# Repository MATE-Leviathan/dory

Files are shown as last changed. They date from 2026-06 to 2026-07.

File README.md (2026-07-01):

# Dory

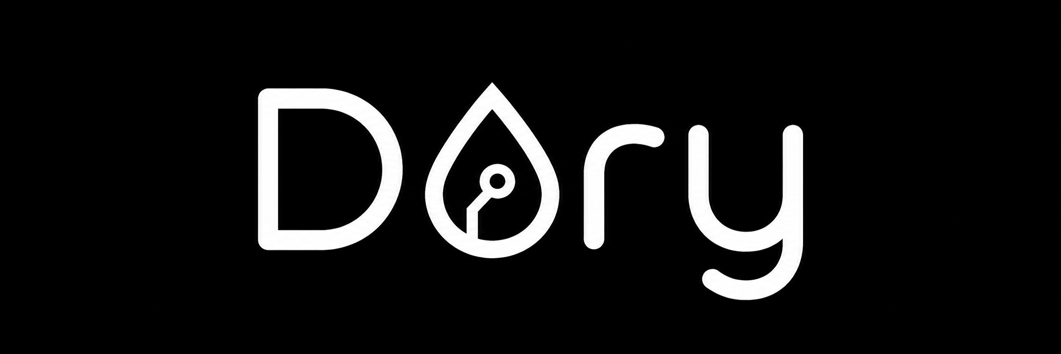
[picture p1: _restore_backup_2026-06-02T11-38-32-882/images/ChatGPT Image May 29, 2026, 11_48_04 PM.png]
Dory project logo


A custom control and power distribution board for NCSSM Morganton Robotics.

NCSSM Morganton Robotics

## Why this exists

This board started as a wiring problem.

On the robot, too many things were being connected with loose jumper wires, splitters, adapters, and one-off harnesses. It worked, but it was annoying to build, annoying to trace, and even more annoying to debug when something came loose. Every extra wire was another failure point, and every repair meant spending time figuring out which connection had moved instead of working on the robot.

Float PCB is meant to clean that up. It brings the common controller, power, sensor, light, and debug connections onto one board so the robot is easier to assemble, easier to service, and less dependent on fragile wiring.

## Board evolution

The design went through several revisions while the board moved from a simple rectangular breakout toward the current round layout with cleaner connector placement, clearer labels, and more intentional branding.

Top-side PCB revision collage

Bottom-side PCB revision collage

## Features

- **ESP32-S3 controller** using an ESP32-S3-WROOM-1U module for onboard control and wireless-capable development.
- **External antenna support** through the ESP32-S3-WROOM-1U module for more flexible radio placement.
- **USB-C interface** for programming, debugging, and convenient bench access.
- **XT30 battery input** for a more robust main power connector than loose leads.
- **64 mm round board outline** for a compact layout that fits cleanly into the robot.
- **4-layer PCB stackup** with front/back signal layers and two internal power layers.
- **5V and 3.3V regulation** using TPSM863252 power modules.
- **ESP-controlled 5V enable** so software can turn the 5V rail on or off when needed.
- **Onboard buzzer** for audible alerts, even when the board is mounted inside the robot.
- **External light output** for driving a Blue Robotics-style indicator or robot status light.
- **Dual I2C ports** on JST-XH connectors for cleaner sensor wiring.
- **Robot I/O connectors** for switch, light, servo, buzzer, and miscellaneous expansion signals.
- **Battery sensing** through a resistor divider and dedicated `BATT_ADC` test point.
- **Status LEDs** for battery, 5V, and 3.3V rails.
- **USB ESD protection** on the USB data lines.
- **Debug/test access** with labeled test points for power rails, boot, enable, I2C, and ground.
- **Mechanical mounting** with three M2 mounting holes.

## Hardware overview

The board is built around an ESP32-S3-WROOM-1U module and breaks out the useful robot-facing signals to keyed or serviceable connectors. The PCB is a 64 mm diameter, 4-layer circular board with front and back signal routing plus two internal power layers. Power enters through an XT30 connector, then the onboard regulators generate the rails needed by the controller and peripherals.

The intent is not to replace every subsystem on the robot. The goal is to provide a cleaner central board for the connections that otherwise turn into messy wiring: power, I2C devices, lights, switches, a buzzer, servo control, battery monitoring, and spare expansion lines.

## Work in progress

The current plan is to use the onboard ESP32 as the robot-side controller and pair it with a separate ESP32-based base station. The base station will communicate with the ESP32 on the Float PCB, giving the robot a cleaner wireless control/debug path without needing to plug directly into the board every time.

An accompanying web interface is also planned. The site will be built with Svelte and use Web Serial so a laptop can talk to the ESP32 base station directly from the browser. The goal is to make setup, monitoring, and debugging accessible without requiring a custom desktop app.

## Repository contents

- `float_pcb.kicad_pro` — KiCad project file.
- `float_pcb.kicad_sch` — schematic source.
- `float_pcb.kicad_pcb` — PCB layout source.
- `jlcpcb/production_files/` — generated BOM, CPL, and Gerber ZIP for JLCPCB.
- `jlcpcb/gerber/` — expanded Gerber and drill outputs.
- `float_pcb.csv` — project BOM/export data.
- `digikey/order.csv` — DigiKey ordering file.
- `images/` — README and board/team branding assets.

## Manufacturing

The repository includes production outputs under `jlcpcb/production_files/`:

- `GERBER-float_pcb.zip`
- `BOM-float_pcb.csv`
- `CPL-float_pcb.csv`

Before ordering, re-open the project in KiCad, refill zones, run DRC/ERC, and regenerate production files from the latest schematic and PCB layout. The checked-in files are useful for handoff, but the KiCad sources should be treated as the source of truth.

For component ordering, use `digikey/order.csv` as the DigiKey order file.

## Known issues

- One of the I2C ports is about 0.025 mm off in the Z direction. This is only for people with OCD like me; it should not matter for normal assembly.
- The fancy QFN buck converter packages are hard to solder by hand. If you want to build this board, make sure you have solder paste, reflow, and patience, or redesign that power stage around something friendlier like a SOT-23 package.

## Development notes

- Designed in KiCad.
- Uses mostly SMD passives with JST-XH, XT30, USB-C, and pin-header connections.
- Includes test points for bring-up and debugging.
- Intended for robotics use where reliability and serviceability matter more than minimizing every connector or square millimeter.

## Team

Built for NCSSM Morganton Robotics as a practical fix for too much robot wiring.

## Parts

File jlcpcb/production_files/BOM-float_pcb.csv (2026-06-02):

Comment | Designator | Footprint | LCSC | Quantity
Light | J6 | JST_XH_B2B-XH-A_1x02_P2.50mm_Vertical |  | 1
Switch | J1 | JST_XH_B2B-XH-A_1x02_P2.50mm_Vertical |  | 1
22u | C14 | C_0603_1608Metric |  | 1
100n | C7 | C_0603_1608Metric |  | 1
28k7 | R6 | R_0603_1608Metric |  | 1
AO3400A | Q1 | SOT-23 |  | 1
22p | C4 | C_0603_1608Metric |  | 1
5V | D3 | LED_0603_1608Metric |  | 1
2k2 | R16 | R_0603_1608Metric |  | 1
100n | C2 | C_0603_1608Metric |  | 1
5k1 | R11 | R_0603_1608Metric |  | 1
10n | C3 | C_0603_1608Metric |  | 1
10k | R7 | R_0603_1608Metric |  | 1
33u | C5 | C_0805_2012Metric |  | 1
TPSM863252 | U2 | TPSM86325x_RDX0007A |  | 1
100n | C13 | C_0603_1608Metric |  | 1
1u | C12 | C_0603_1608Metric |  | 1
10k | R3 | R_0603_1608Metric |  | 1
220k | R8 | R_0603_1608Metric |  | 1
SW_Push | BOOT1 | SW_SPST_TL3342 |  | 1
10u | C6 | C_0805_2012Metric |  | 1
10k | R12 | R_0603_1608Metric |  | 1
4k7 | R13 | R_0603_1608Metric |  | 1
28k7 | R2 | R_0603_1608Metric |  | 1
Batt | J7 | AMASS_XT30U-M_1x02_P5.0mm_Vertical |  | 1
33u | C10 | C_0805_2012Metric |  | 1
4k7 | R14 | R_0603_1608Metric |  | 1
135k | R4 | R_0603_1608Metric |  | 1
10u | C1 | C_0805_2012Metric |  | 1
4k7 | R1 | R_0603_1608Metric |  | 1
USB_C | J3 | USB_C_Receptacle_GCT_USB4105-xx-A_16P_TopMnt_Horizontal |  | 1
30k | R9 | R_0603_1608Metric |  | 1
1k | R15 | R_0603_1608Metric |  | 1
3V3 | D2 | LED_0603_1608Metric |  | 1
TPSM863252 | U1 | TPSM86325x_RDX0007A |  | 1
10n | C8 | C_0603_1608Metric |  | 1
I2C | J5 | JST_XH_B4B-XH-A_1x04_P2.50mm_Vertical |  | 1
5k1 | R10 | R_0603_1608Metric |  | 1
30k | R5 | R_0603_1608Metric |  | 1
22p | C9 | C_0603_1608Metric |  | 1
BATT | D1 | LED_0603_1608Metric |  | 1
SW_Push | ENABLE1 | SW_SPST_TL3342 |  | 1
10k | R17 | R_0603_1608Metric |  | 1
4k7 | R19 | R_0603_1608Metric |  | 1
4k7 | R18 | R_0603_1608Metric |  | 1
I2C | J9 | JST_XH_B4B-XH-A_1x04_P2.50mm_Vertical |  | 1
10k | R20 | R_0603_1608Metric |  | 1
AO3400A | Q2 | SOT-23 |  | 1
AT-1127-ST-2-R | LS1 | XDCR_AT-1127-ST-2-R |  | 1
Conn_01x03 | J4 | JST_XH_B3B-XH-A_1x03_P2.50mm_Vertical |  | 1
ESP32-S3-WROOM-1 | U4 | ESP32-S3-WROOM-1U |  | 1
Conn_01x04 | J2 | PinHeader_1x04_P2.54mm_Vertical |  | 1
BATT | TP4 | TestPoint_Pad_D1.5mm |  | 1
GND | TP3 | TestPoint_Pad_D1.5mm |  | 1
3V3 | TP2 | TestPoint_Pad_D1.5mm |  | 1
5V | TP1 | TestPoint_Pad_D1.5mm |  | 1
USBLC6-2SC6 | U3 | SOT-23-6 |  | 1
USBLC6-4SC6 | U5 | SOT-23-6 |  | 1
USBLC6-4SC6 | U6 | SOT-23-6 |  | 1
TBD | R26 | R_0603_1608Metric |  | 1
10k | R25 | R_0603_1608Metric |  | 1
10k | R24 | R_0603_1608Metric |  | 1
10k | R23 | R_0603_1608Metric |  | 1
10k | R22 | R_0603_1608Metric |  | 1
0 | R21 | R_0603_1608Metric |  | 1
EN | TP10 | TestPoint_Pad_D1.5mm |  | 1
SDA2 | TP6 | TestPoint_Pad_D1.5mm |  | 1
BOOT | TP9 | TestPoint_Pad_D1.5mm |  | 1
SCL2 | TP5 | TestPoint_Pad_D1.5mm |  | 1
SDA2 | TP7 | TestPoint_Pad_D1.5mm |  | 1
SCL1 | TP8 | TestPoint_Pad_D1.5mm |  | 1

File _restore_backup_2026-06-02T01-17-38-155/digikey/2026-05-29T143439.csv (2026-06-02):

Index | Quantity | Part Number | Manufacturer Part Number | Description | Customer Reference | Available | Backorder | Unit Price | Extended Price USD
1 | 10 | 296-TPSM863252RDXRCT-ND | TPSM863252RDXR | 3-V TO 17-V INPUT VOLTAGE 3-A E |  | 10 | 0 | 2.01900 | 20.19
2 | 100 | 311-10.0KHRCT-ND | RC0603FR-0710KL | RES 10K OHM 1% 1/10W 0603 |  | 100 | 0 | 0.01220 | 1.22
3 | 100 | 160-1447-1-ND | LTST-C191KRKT | LED RED CLEAR SMD |  | 100 | 0 | 0.04740 | 4.74
4 | 10 | 785-1000-1-ND | AO3400A | MOSFET N-CH 30V 5.7A SOT23-3L |  | 10 | 0 | 0.32200 | 3.22
5 | 100 | 311-4.7KGRCT-ND | RC0603JR-074K7L | RES 4.7K OHM 5% 1/10W 0603 |  | 100 | 0 | 0.01080 | 1.08
6 | 10 | EG5470CT-ND | TL3342F260QG | SWITCH TACTILE SPST-NO 0.05A 12V |  | 10 | 0 | 0.50600 | 5.06
7 | 10 | 311-28.7KHRCT-ND | RC0603FR-0728K7L | RES 28.7K OHM 1% 1/10W 0603 |  | 10 | 0 | 0.02500 | 0.25
8 | 10 | 311-30.0KHRCT-ND | RC0603FR-0730KL | RES 30K OHM 1% 1/10W 0603 |  | 10 | 0 | 0.02500 | 0.25
9 | 10 | 311-5.10KHRCT-ND | RC0603FR-075K1L | RES 5.1K OHM 1% 1/10W 0603 |  | 10 | 0 | 0.02500 | 0.25
10 | 3 | 1965-ESP32-S3-WROOM-1U-N8R8CT-ND | ESP32-S3-WROOM-1U-N8R8 | RF TXRX MOD BLUETOOTH U.FL SMD |  | 3 | 0 | 6.32000 | 18.96
11 | 5 | 2073-USB4105-GF-ACT-ND | USB4105-GF-A | CONN RCP USB2.0 TYP C 16P SMD RA |  | 5 | 0 | 0.80000 | 4.00
12 | 3 | 668-1463-ND | AT-1127-ST-2-R | BUZZER MAGNETIC 3V 9MM TH |  | 3 | 0 | 1.09000 | 3.27
13 | 10 | 311-30.0KHRCT-ND | RC0603FR-0730KL | RES 30K OHM 1% 1/10W 0603 |  | 10 | 0 | 0.02500 | 0.25
14 | 10 | 311-1.00KHRCT-ND | RC0603FR-071KL | RES 1K OHM 1% 1/10W 0603 |  | 10 | 0 | 0.02500 | 0.25
15 | 10 | 311-2.20KHRCT-ND | RC0603FR-072K2L | RES 2.2K OHM 1% 1/10W 0603 |  | 10 | 0 | 0.02500 | 0.25
16 | 10 | 311-220KHRCT-ND | RC0603FR-07220KL | RES 220K OHM 1% 1/10W 0603 |  | 10 | 0 | 0.02500 | 0.25
17 | 10 | 13-RT0603BRD07135KLCT-ND | RT0603BRD07135KL | RES SMD 135K OHM 0.1% 1/10W 0603 |  | 10 | 0 | 0.06700 | 0.67
18 | 10 | 1276-1096-1-ND | CL21A106KOQNNNE | CAP CER 10UF 16V X5R 0805 |  | 10 | 0 | 0.05400 | 0.54
19 | 10 | 1276-1070-1-ND | CL10C330JB8NNNC | CAP CER 33PF 50V C0G/NP0 0603 |  | 10 | 0 | 0.03800 | 0.38
20 | 10 | 1276-1023-1-ND | CL10C220JB8NNNC | CAP CER 22PF 50V C0G/NP0 0603 |  | 10 | 0 | 0.03800 | 0.38
21 | 10 | 1276-1274-1-ND | CL10A226MP8NUNE | CAP CER 22UF 10V X5R 0603 |  | 10 | 0 | 0.08900 | 0.89
22 | 10 | 1276-1019-1-ND | CL10B105KO8NNNC | CAP CER 1UF 16V X7R 0603 |  | 10 | 0 | 0.03700 | 0.37
23 | 10 | 1276-1000-1-ND | CL10B104KB8NNNC | CAP CER 0.1UF 50V X7R 0603 |  | 10 | 0 | 0.02700 | 0.27
24 | 10 | 1276-1009-1-ND | CL10B103KB8NNNC | CAP CER 10000PF 50V X7R 0603 |  | 10 | 0 | 0.02500 | 0.25

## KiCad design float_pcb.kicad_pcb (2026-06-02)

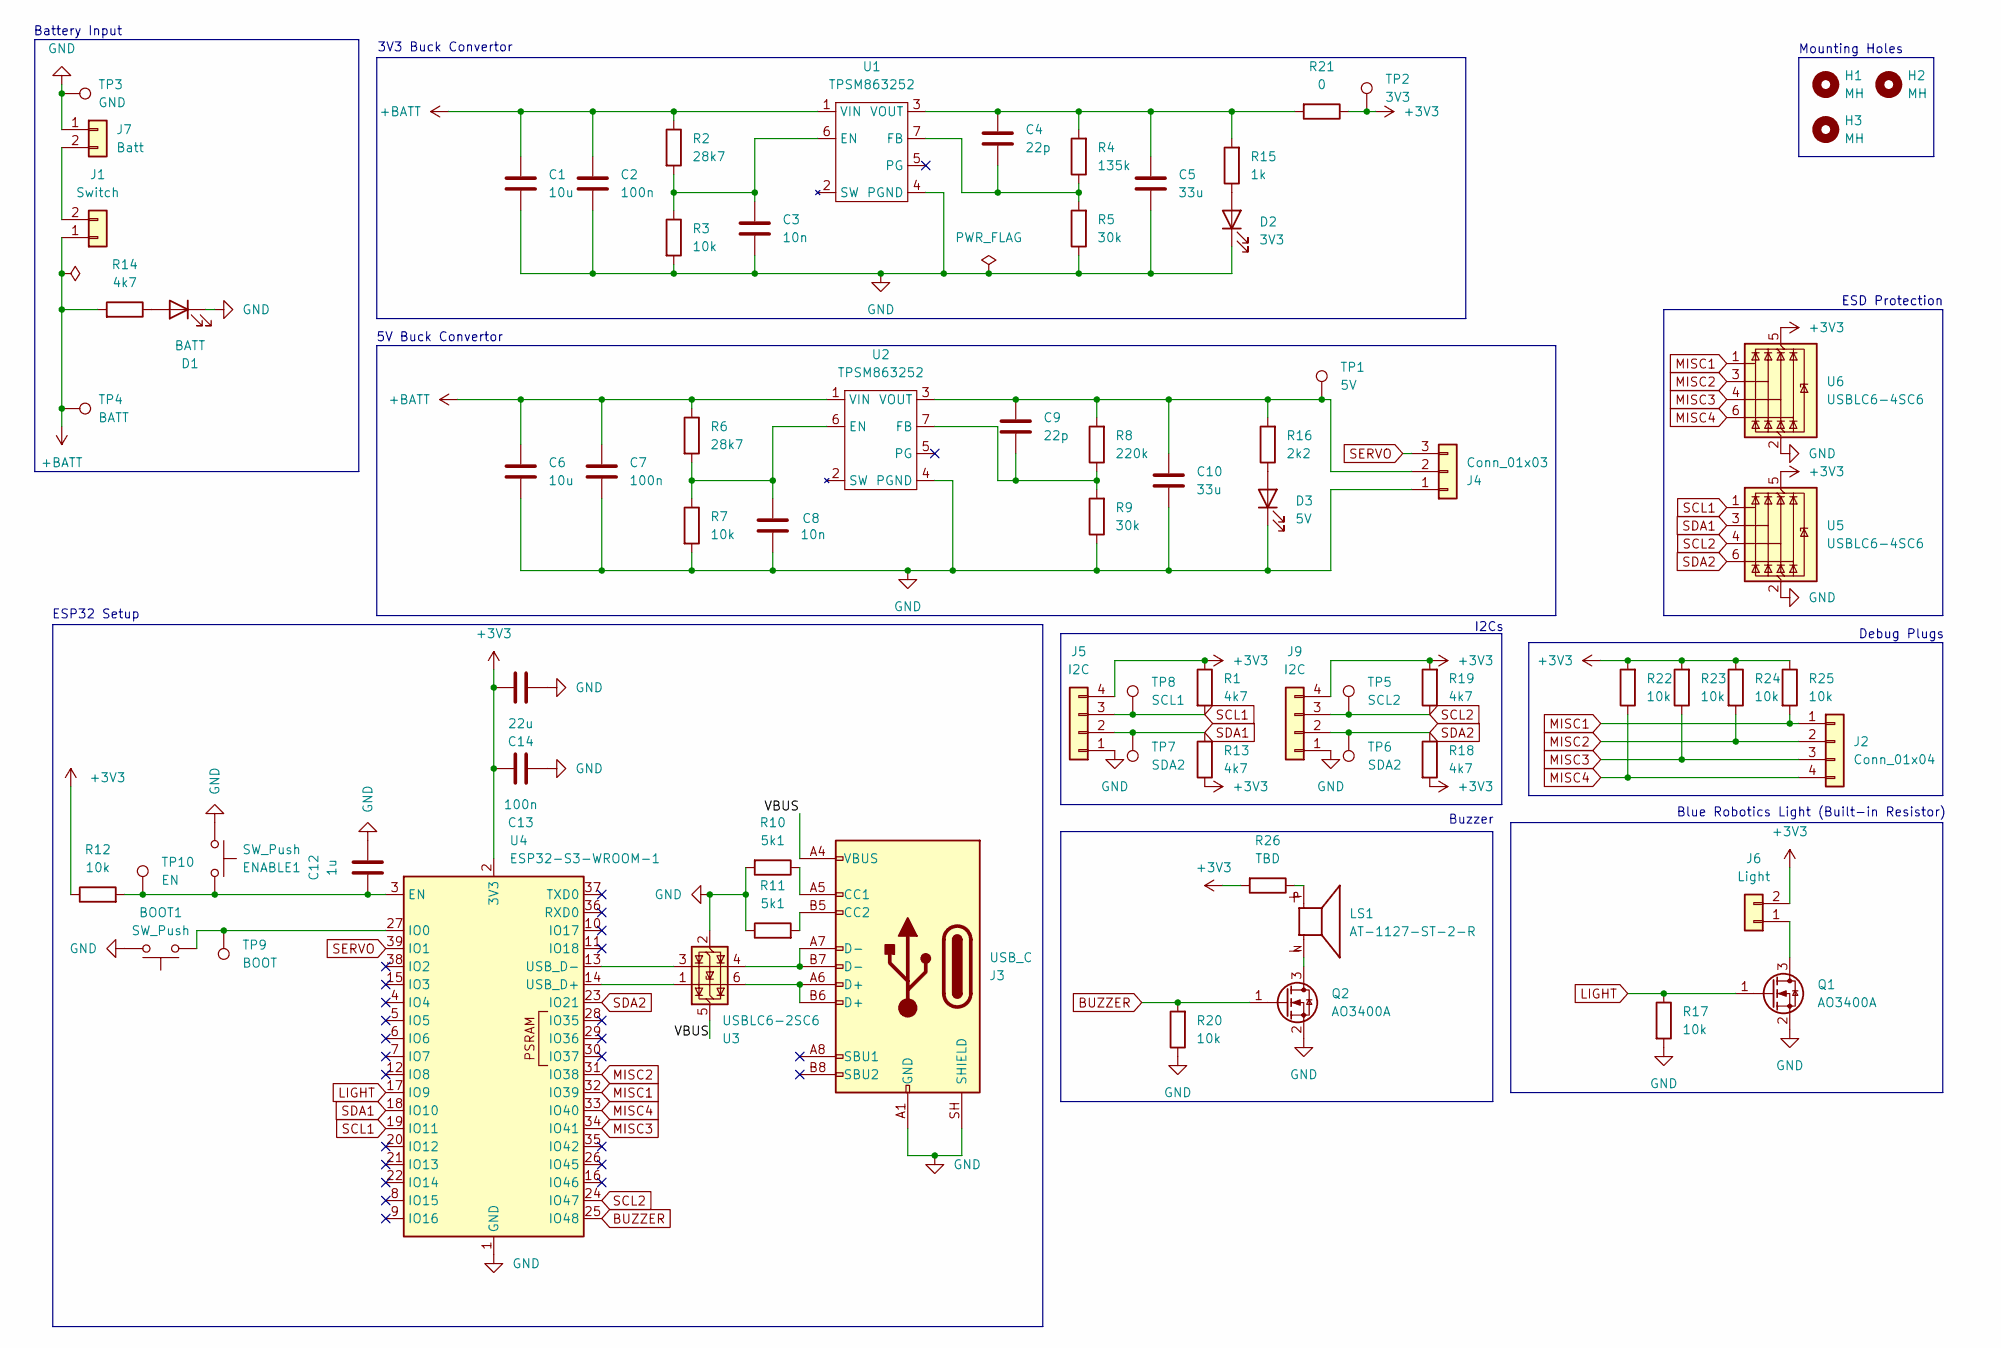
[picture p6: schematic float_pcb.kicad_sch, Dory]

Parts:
BOOT1: SW_Push; SW_SPST_TL3342
C1, C6: 10u; C_0805_2012Metric
C2, C7, C13: 100n; C_0603_1608Metric
C3, C8: 10n; C_0603_1608Metric
C4, C9: 22p; C_0603_1608Metric
C5, C10: 33u; C_0805_2012Metric
C12: 1u; C_0603_1608Metric
C14: 22u; C_0603_1608Metric
D1: BATT; LED_0603_1608Metric
D2: 3V3; LED_0603_1608Metric
D3: 5V; LED_0603_1608Metric
ENABLE1: SW_Push; SW_SPST_TL3342
H1, H2, H3: MH; MountingHole_2.2mm_M2
J1: Switch; JST_XH_B2B-XH-A_1x02_P2.50mm_Vertical
J2: Conn_01x04; PinHeader_1x04_P2.54mm_Vertical
J3: USB_C; USB_C_Receptacle_GCT_USB4105-xx-A_16P_TopMnt_Horizontal
J4: Conn_01x03; JST_XH_B3B-XH-A_1x03_P2.50mm_Vertical
J5, J9: I2C; JST_XH_B4B-XH-A_1x04_P2.50mm_Vertical
J6: Light; JST_XH_B2B-XH-A_1x02_P2.50mm_Vertical
J7: Batt; AMASS_XT30U-M_1x02_P5.0mm_Vertical
LS1: AT-1127-ST-2-R; XDCR_AT-1127-ST-2-R; PARTREV C
Q1, Q2: AO3400A; SOT-23
R1, R13, R14, R18, R19: 4k7; R_0603_1608Metric
R2, R6: 28k7; R_0603_1608Metric
R3, R7, R12, R17, R20, R22, R23, R24, R25: 10k; R_0603_1608Metric
R4: 135k; R_0603_1608Metric
R5, R9: 30k; R_0603_1608Metric
R8: 220k; R_0603_1608Metric
R10, R11: 5k1; R_0603_1608Metric
R15: 1k; R_0603_1608Metric
R16: 2k2; R_0603_1608Metric
R21: 0; R_0603_1608Metric
R26: TBD; R_0603_1608Metric
TP1: 5V; TestPoint_Pad_D1.5mm
TP2: 3V3; TestPoint_Pad_D1.5mm
TP3: GND; TestPoint_Pad_D1.5mm
TP4: BATT; TestPoint_Pad_D1.5mm
TP5: SCL2; TestPoint_Pad_D1.5mm
TP6, TP7: SDA2; TestPoint_Pad_D1.5mm
TP8: SCL1; TestPoint_Pad_D1.5mm
TP9: BOOT; TestPoint_Pad_D1.5mm
TP10: EN; TestPoint_Pad_D1.5mm
U1, U2: TPSM863252; TPSM86325x_RDX0007A
U3: USBLC6-2SC6; SOT-23-6
U4: ESP32-S3-WROOM-1; ESP32-S3-WROOM-1U
U5, U6: USBLC6-4SC6; SOT-23-6

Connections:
+3V3: C13.1, C14.1, J5.4, J6.2, J9.4, R1.1, R12.1, R13.1, R18.2, R19.2, R21.1, R22.2, R23.2, R24.1, R25.1, R26.2, TP2.1 (1_1), U4.2 (3V3), U5.5 (VBUS), U6.5 (VBUS)
+BATT: C1.1, C2.2, C6.1, C7.2, J1.1, R2.1, R6.1, R14.2, TP4.1 (1_1), U1.1 (VIN), U2.1 (VIN)
/VBUS: J3.A4 (VBUS), J3.A9 (VBUS), J3.B4 (VBUS), J3.B9 (VBUS), U3.5 (VBUS)
BUZZER: Q2.1 (G), R20.2, U4.25 (IO48)
GND: BOOT1.2, C1.2, C2.1, C3.1, C5.1, C6.2, C7.1, C8.2, C10.1, C12.1, C13.2, C14.2, D1.1 (K), D2.1 (K), D3.1 (K), ENABLE1.1, J3.A1 (GND), J3.A12 (GND), J3.B1 (GND), J3.B12 (GND), J3.SH (SHIELD), J4.1, J5.1, J7.1, J9.1, Q1.2 (S), Q2.2 (S), R3.2, R5.1, R7.2, R9.1, R10.2, R11.1, R17.2, R20.1, TP3.1 (1_1), U1.4 (PGND), U2.4 (PGND), U3.2 (GND), U4.1 (GND), U4.40 (GND), U4.41 (GND), U5.2 (GND), U6.2 (GND)
LIGHT: Q1.1 (G), R17.1, U4.17 (IO9)
MISC1: J2.1, R25.2, U4.32 (IO39), U6.1 (I/O1)
MISC2: J2.2, R24.2, U4.31 (IO38), U6.3 (I/O2)
MISC3: J2.3, R23.1, U4.34 (IO41), U6.4 (I/O3)
MISC4: J2.4, R22.1, U4.33 (IO40), U6.6 (I/O4)
unnamed: D1.2 (A), R14.1
unnamed: D2.2 (A), R15.1
unnamed: D3.2 (A), R16.1
unnamed: J1.2, J7.2
unnamed: J3.A5 (CC1), R10.1
unnamed: J3.B5 (CC2), R11.2
unnamed: J3.A6 (D+), J3.B6 (D+), U3.6 (I/O1)
unnamed: J3.A7 (D-), J3.B7 (D-), U3.4 (I/O2)
unnamed: C9.1, C10.2, J4.2, R8.2, R16.2, TP1.1 (1_1), U2.3 (VOUT)
unnamed: J6.1, Q1.3 (D)
unnamed: LS1.P, R26.1
unnamed: LS1.N, Q2.3 (D)
unnamed: C3.2, R2.2, R3.1, U1.6 (EN)
unnamed: C4.2, R4.1, R5.2, U1.7 (FB)
unnamed: C4.1, C5.2, R4.2, R15.2, R21.2, U1.3 (VOUT)
unnamed: C8.1, R6.2, R7.1, U2.6 (EN)
unnamed: C9.2, R8.1, R9.2, U2.7 (FB)
unnamed: C12.2, ENABLE1.2, R12.2, TP10.1 (1_1), U4.3 (EN)
unnamed: BOOT1.1, TP9.1 (1_1), U4.27 (IO0)
unnamed: U3.1 (I/O1), U4.14 (USB_D+)
unnamed: U3.3 (I/O2), U4.13 (USB_D-)
SCL1: J5.3, R1.2, TP8.1 (1_1), U4.19 (IO11), U5.1 (I/O1)
SCL2: J9.3, R19.1, TP5.1 (1_1), U4.24 (IO47), U5.4 (I/O3)
SDA1: J5.2, R13.2, TP7.1 (1_1), U4.18 (IO10), U5.3 (I/O2)
SDA2: J9.2, R18.1, TP6.1 (1_1), U4.23 (IO21), U5.6 (I/O4)
SERVO: J4.3, U4.39 (IO1)

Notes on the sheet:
Mounting Holes
ESP32 Setup
I2Cs
ESD Protection
Battery Input
3V3 Buck Convertor
Blue Robotics Light (Built-in Resistor)
5V Buck Convertor
Buzzer
Debug Plugs

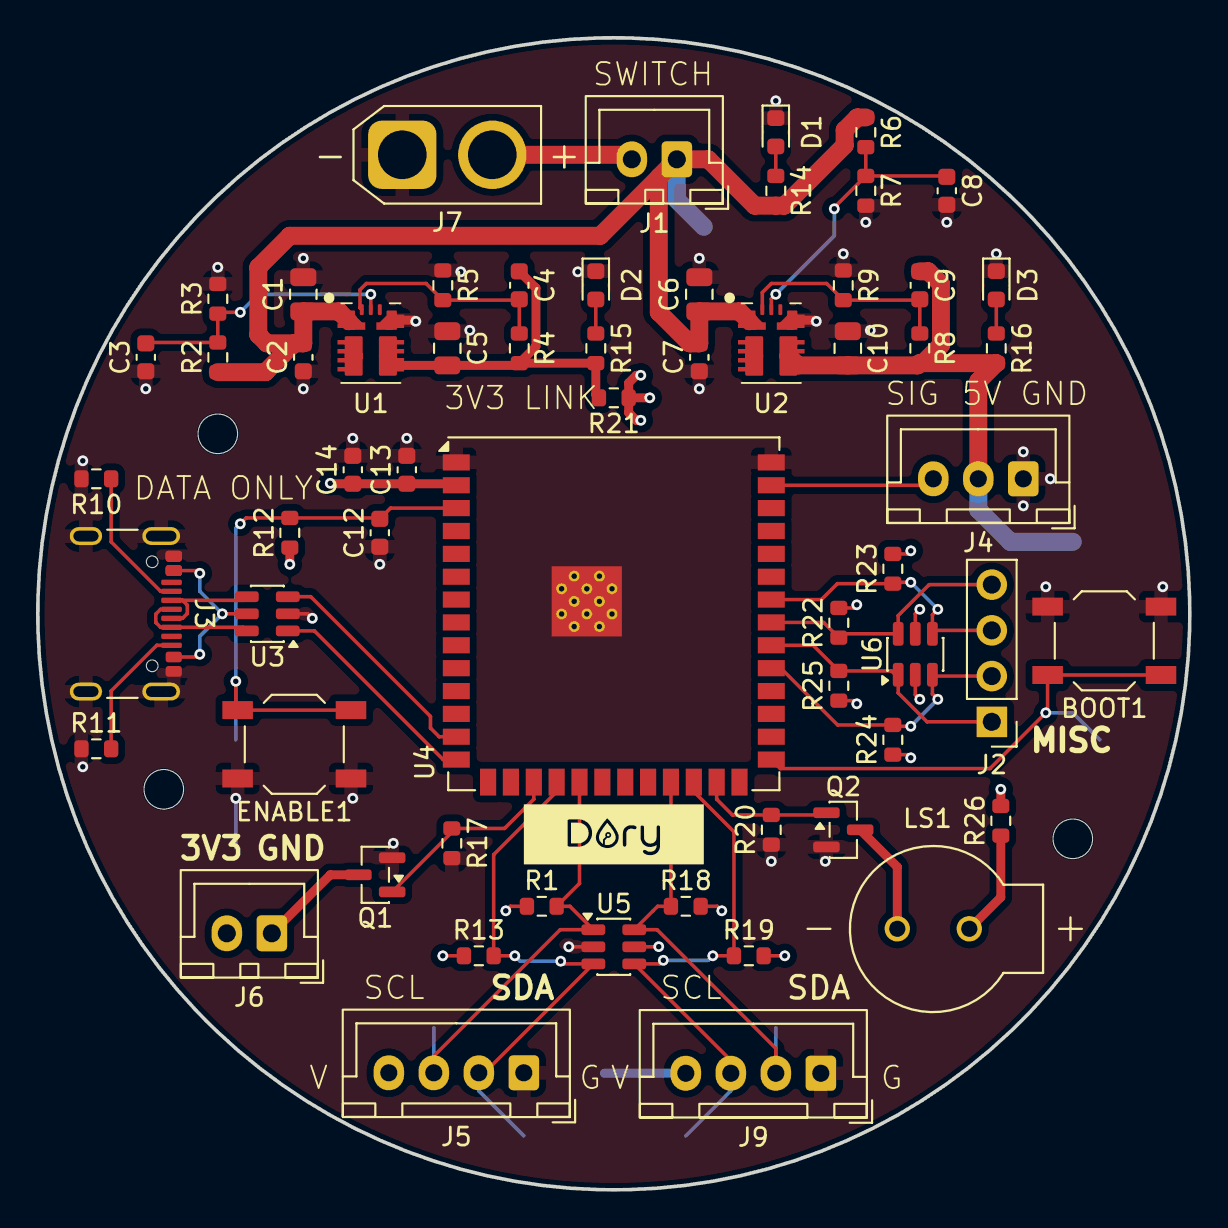
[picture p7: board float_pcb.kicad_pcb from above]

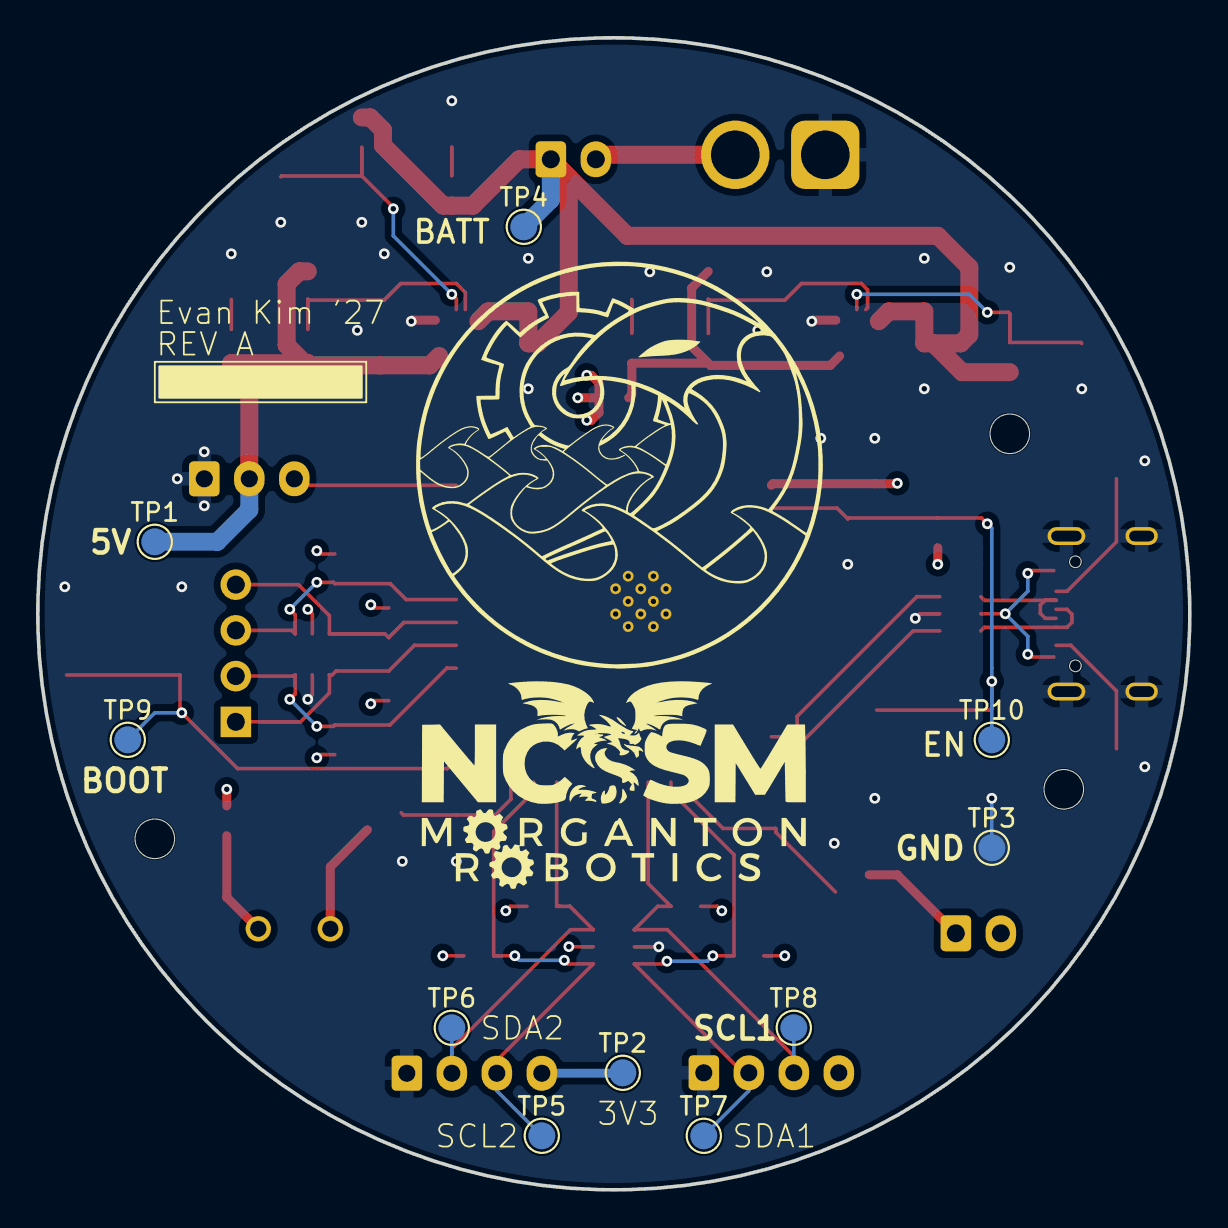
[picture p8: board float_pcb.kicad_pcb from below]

Board: 4 copper layers, 64.0 x 64.0 mm, 74 parts (10 on the bottom side), 36 nets.

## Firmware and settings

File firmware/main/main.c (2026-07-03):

#include "freertos/FreeRTOS.h"
#include "freertos/task.h"
#include "sdkconfig.h"
#include "nvs_flash.h"

#include "board/battery.h"
#include "board/servo.h"
#include "board/buzzer.h"
#include "board/light.h"
#include "com.h"
#include "debug_serial.h"

void app_main(void)
{
    servo_init();
    light_init();
    buzzer_init();
    battery_init();

#ifdef CONFIG_DORY_DEBUG_SERIAL
    debug_serial_start();
#endif

#ifdef CONFIG_DORY_WIRELESS
    // Initialize NVS
    esp_err_t ret = nvs_flash_init();
    if (ret == ESP_ERR_NVS_NO_FREE_PAGES || ret == ESP_ERR_NVS_NEW_VERSION_FOUND) {
        ESP_ERROR_CHECK( nvs_flash_erase() );
        ret = nvs_flash_init();
    }
    ESP_ERROR_CHECK( ret );

    init_com();
#endif

    light_set(true);
    buzzer_play_samsung_boot();
    light_set(false);

    while (1) {
        vTaskDelay(pdMS_TO_TICKS(1000));
    }
}

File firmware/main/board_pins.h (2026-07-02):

#pragma once

#include "driver/gpio.h"
#include "hal/adc_types.h"

#define EN_5V_PIN GPIO_NUM_16
#define BATT_ADC_PIN GPIO_NUM_4
#define BATT_ADC_CHANNEL ADC_CHANNEL_3
#define LIGHT_PIN GPIO_NUM_9
#define BUZZER_PIN GPIO_NUM_48

// 220k and 100k voltage divider
#define BATT_DIVIDER_MULTIPLIER 3.2f

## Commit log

2026-05-18 Add some things
    [float_pcb.kicad_sch]
2026-05-18 more changes
    [float_pcb.kicad_pcb, float_pcb.kicad_sch]
2026-06-02 Almost done with V4
    [2026-05-29T143439.csv, 2026-05-29T144358.csv, BOM-float_pcb.csv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]
2026-07-05 Make mission truly boiler plate
2026-11-08 feat: add MS5837 driver submodule
2026-11-08 feat: add Bar02 sensor readings and startup warning beeps
2026-11-08 feat: report sensor depth in state replies with unavailable sentinel
